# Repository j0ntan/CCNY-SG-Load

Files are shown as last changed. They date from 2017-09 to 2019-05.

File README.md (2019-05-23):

# CCNY Smart Grid Load

The Smart Grid Load (*SG-Load*) is a resistive, variable load component of the smart grid testbed at the Smart Grid Lab in the City College of New York. This project implements a control system for the SG-Load that allows:

* Setting the value of 3-phase AC loading to a balanced or unbalanced state.
* Varying the amount of loading for a DC source.
* Automating the amount of loading over time according to a load profile.

## Getting Started
This section summarizes the steps needed to upload the control system sketch to the Arduino and begin using the SG-Load through the keypad interface.\
*Note: The Arduino should already have the latest sketch version uploaded. The installation steps are only needed when debugging or upgrading this sketch.*

### Install & Run
1. [Download](https://github.com/j0ntan/CCNY-SG-Load/archive/master.zip) or clone ( `git clone https://github.com/j0ntan/CCNY-SG-Load.git` ) the repo into your **Arduino sketchbook location** directory, which may be under `{YourUserName}\Documents\Arduino` on a Windows machine.
2. Install the [New LiquidCrystal](https://bitbucket.org/fmalpartida/new-liquidcrystal) library, which replaces the usage of the default LCD library.
3. Open & upload the `CCNY_Smart_Grid_Load.ino` sketch using the Arduino IDE.
4. Switch the Arduino to external power and observe the LCD startup message to verify the sketch upload.

### Basic Input
The simplest way to control the SG-Load is with the front-panel keypad. Let's say we want to set up an unbalanced load at the AC terminals, with 10 switches turned ON for phases A & B, but only 9 for phase C. We can enter the sequence `A10B10C9`, or equivalently `AB10C9`, followed by the ENTER key (`#`), to activate this configuration.

The Arduino can also take input from an XBee-connected PC or the lab's dSPACE controller. These methods are slightly more complex and their descriptions are reserved for the wiki.

---
For further details on the installation & build process, system configurations and working with the SG-Load, check out the [wiki](https://github.com/j0ntan/CCNY-SG-Load/docs/wiki) documentation.

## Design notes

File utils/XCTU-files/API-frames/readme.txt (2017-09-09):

This directory contains frames that can be sent to an XBee device using the XCTU software by Digi. The frames contain a payload that is transmitted by the XBee device. This allows us to test different inputs by XBee transmission.

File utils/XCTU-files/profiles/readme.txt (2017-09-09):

This directory contains the XBee profiles for XBee devices connected to the Smart Grid Load and to a microgrid central controller (MGCC). Currently, the MGCC is a dSPACE controller. The current configuration uses the AT mode, for simplicity (refer to XBee docs regarding AT vs API mode). A future, more secure implementation will utilize the API mode with the built-in encryption.

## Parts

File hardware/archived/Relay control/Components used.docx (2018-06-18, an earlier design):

Components used:

Mux Shield (DEPRECATED)

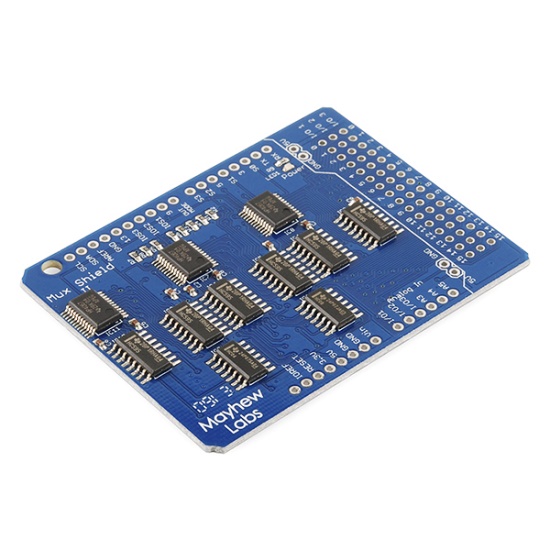
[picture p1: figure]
Mux Shield II

| User Guide (http://cdn.sparkfun.com/datasheets/Dev/Arduino/Shields/Mux_Shield_II_User_Guide.pdf) schematic (http://cdn.sparkfun.com/datasheets/Dev/Arduino/Shields/Mux_Shield_II_Rev0%20Schematic.pdf) Arduino library (http://cdn.sparkfun.com/datasheets/Dev/Arduino/Shields/MuxShield.zip)

74HCT373N OCTAL D TYPE TRANS LATCH, 3-STATE (DEPRECATED)

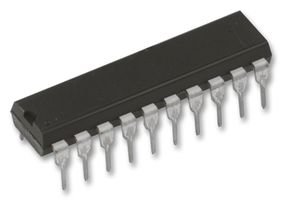
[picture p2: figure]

SainSmart IIC/I2C/TWI Serial 2004 20x4 LCD Module Shield for Arduino Raspberry Pi

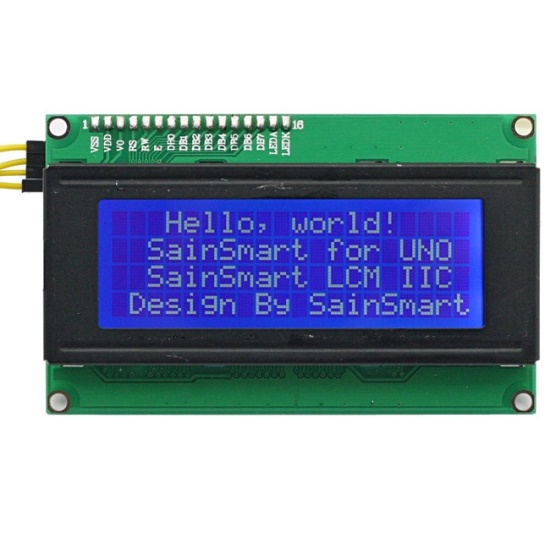
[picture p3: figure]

| module link (http://www.sainsmart.com/sainsmart-iic-i2c-twi-serial-2004-20x4-lcd-module-shield-for-arduino-uno-mega-r3.html) For using with Arduino, look at these links with libraries that are used in the relay code, instead of the default Arduino LCD library: 1 (https://bitbucket.org/fmalpartida/new-liquidcrystal/wiki/Home), 2 (https://bitbucket.org/fmalpartida/new-liquidcrystal/downloads), and 3 (https://bitbucket.org/fmalpartida/new-liquidcrystal/wiki/I2CIO). For connecting the module to Arduino, use the I2Cscanner code found here (http://arduinotronics.blogspot.com/2014/02/sainsmart-i2c-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

SainSmart 8 Channel DC 5V Relay Module for Arduino Raspberry Pi

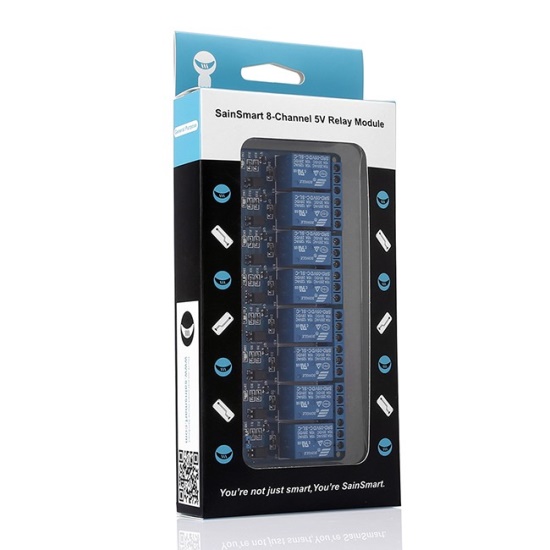
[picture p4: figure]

| module link (http://www.sainsmart.com/8-channel-dc-5v-relay-module-for-arduino-pic-arm-dsp-avr-msp430-ttl-logic.html) other docs (http://www.selloutsoon.com/albums/documents/20-018-102/8+Relay+Module.rar)

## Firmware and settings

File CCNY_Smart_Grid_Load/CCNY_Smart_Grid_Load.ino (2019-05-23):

// Author: Jonathan Gamboa
// version: 5.11.0
// Institution: Smart Grid Lab, City College of New York (ST 643)

#include "include/HardwareTimer.h"
#include "include/HardwareIO.h"
#include "include/HardwareKeypad.h"
#include "include/HardwareXBee.h"
#include "include/HardwareSDFlash.h"
#include "include/HardwareRNG.h"
#include "include/Display/HardwareLCD.h"
#include "include/InputSequence.h"
#include "include/LoadProfile.h"
#include "include/Monitor.h"
#include "include/Collect.h"
#include "include/RelayState.h"
#include "include/RelayStateGenerator.h"
#include "include/ShiftRegister.h"
#include "include/Output.h"
#include "include/Display/MessagesList.h"
#include "include/Display/StatusMsgSequences.h"

//
// SG-Load Arduino I/O pin mapping:
//
// Keypad outputs
const DigitalInput* row1 = new HardwareInput{37};
const DigitalInput* row2 = new HardwareInput{36};
const DigitalInput* row3 = new HardwareInput{35};
const DigitalInput* row4 = new HardwareInput{34};
const DigitalOutput* col1 = new HardwareOutput{33};
const DigitalOutput* col2 = new HardwareOutput{32};
const DigitalOutput* col3 = new HardwareOutput{31};
const DigitalOutput* col4 = new HardwareOutput{30};
const DigitalInput* input_pins[] = {row1, row2, row3, row4};
const DigitalOutput* output_pins[] = {col1, col2, col3, col4};
// Shift register outputs
const DigitalOutput* serial_data_output = new HardwareOutput{2};
const DigitalOutput* SR_clock_output = new HardwareOutput{3};
const DigitalOutput* ST_clock_output = new HardwareOutput{4};
// DC relay outputs
const DigitalOutput* relay1_output = new HardwareOutput{22};
const DigitalOutput* relay2_output = new HardwareOutput{23};

RelayState relay_state;
Timer* timer = new HardwareTimer;
Keypad* keypad = new HardwareKeypad{input_pins, output_pins};
ShiftRegister shiftregister{serial_data_output, SR_clock_output,
                            ST_clock_output};
XBee* xbee = new HardwareXBee{Serial};
SDFlash* sd = new HardwareSDFlash{53};
BernoulliRNG* rng = new HardwareRNG(0.2);
Display::LCD* lcd = new Display::HardwareLCD(0x27);

void setup() {
  Serial.begin(9600);
  Serial.setTimeout(10);
  Display::initializationSequence(*rng);
}

void loop() {
  InputSequence user_input;
  if (keypadButtonWasPressed()) {
    user_input = collectKeypadSequence();
    processInputSequence(user_input);
  } else if (xbee->hasBufferedData()) {
    if (receivedPCSerialData()) {
      user_input = collectPCSequence();
      processInputSequence(user_input);
    } else if (receivedDSPACEManualData()) {
      user_input = collectDSPACESequence();
      processInputSequence(user_input);
    } else if (receivedDSPACELoadProfile()) {
      activateLoadProfile();
    } else
      xbee->clearBuffer();
  }
}

void processInputSequence(const InputSequence& input) {
  if (isValidSequence(input)) {
    recordNewRelayState(input, relay_state);
    outputNewRelayState(relay_state);
    lcd->printMsg(Display::load_idle_state);
    Display::updateIdleState(relay_state);
  }
  // else, display error message
}

void activateLoadProfile() {
  unsigned int number = readRequestedProfileNumber();
  char filename[12] = {"PRFL000.txt"};
  createFilename(number, filename);

  if (sd->connected() && sd->fileExists(filename)) {
    LoadProfile profile{sd->openFile(filename)};
    while (profile.lineAvailable()) {
      InputSequence profile_input;
      unsigned long duration = 0;
      profile.readLine(profile_input, duration);
      processInputSequence(profile_input);
      timer->delay(duration);
    }
  } else
    lcd->printMsg(Display::SD_file_open_error);
}

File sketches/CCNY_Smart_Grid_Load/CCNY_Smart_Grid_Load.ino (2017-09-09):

// Author: Jonathan Gamboa
// version: 4.3
// Institution: Smart Grid Lab, City College of New York (ST 643)

#include <LoadEmulator.h>

void processInput(const String &);      // function prototype

HardwareSerial &xbee = Serial3;         // create an alias
Keypad keypad;                          // use default pins
Display disp(Serial, xbee, keypad);     // use default pins
SDprofile sd;                           // record SD connected status
ShiftRegister shiftReg(7, 5, 6, 4);     // chosen pins for shift register

Encoder encoder;

void setup() {
    Serial.begin(19200); Serial.setTimeout(10);
    xbee.begin(9600); xbee.setTimeout(10);
    shiftReg.begin();

    disp.begin(20, 4);                  // pass num of cols and rows

    // initialize DC relays
    pinMode(22, OUTPUT);
    pinMode(23, OUTPUT);
    digitalWrite(22, LOW);
    digitalWrite(23, LOW);

    // Done with Arduino initialization, now check SD card

    if(sd.checkConnected()==false) {
        String sdConnMsg;
        sdConnMsg.concat( F("    SD card not     ") );
        sdConnMsg.concat( F(" detected. Initial  ") );
        sdConnMsg.concat( F("check failed. Please") );
        sdConnMsg.concat( F("re-check connection.") );

        disp.showMessage(sdConnMsg, Display::Speed::SLOW);
    }

    // Done all initializations, go into idle state
    disp.showMessage(encoder.getIdleState(), Display::Speed::STATIC);
}

void loop() {
    if(keypad.isPressed()) {
        KeypadCol kCol(keypad);
        while(kCol.isCollecting())
            if(keypad.isPressed()) {
                kCol.collectKeypress();
                disp.showMessage(kCol.getColMsg(), kCol.getSpeed()); // update display
                kCol.waitKeyRelease();
            } // else do nothing in-between keypresses, until done collecting

        // send to scanner, etc...
        if(kCol.getInput().length()) processInput(kCol.getInput());
        else disp.showMessage(encoder.getIdleState(), Display::Speed::STATIC);
    } // end if, check keypad source
    else if(Serial.available()) {
        // allow buffer time to fill
        delay(10);

        SerialCol serCol(Serial.readString());
        disp.showMessage(serCol.getColMsg(), serCol.getSpeed()); // update display
        processInput(serCol.getInput());
    }
    else if(xbee.available()) {
        // allow buffer time to fill
        delay(200);

        if(xbee.available() < 12) { // dSPACE spams with data, User doesn't
            SerialCol xbCol(xbee.readString());
            disp.showMessage(xbCol.getColMsg(), xbCol.getSpeed()); // update display
            processInput(xbCol.getInput());
        }
        else {
            dspaceCol dsCol(xbee);
            if(dsCol.profileModeRequested()) {
                dsProfileCol dsPCol(xbee, sd);
                if(dsPCol.openFile()) {
                    disp.showMessage(dsPCol.getColMsg(), dsPCol.getSpeed());// display file opened msg

                    while(dsPCol.isCollecting())
                        if(dsPCol.readLine()) {
                            processInput(dsPCol.getInput());
                            delay(dsPCol.getDelay());
                        }
                }
                else {
                    disp.showMessage(dsPCol.getColMsg(), dsPCol.getSpeed()); // display error msg
                    disp.showMessage(encoder.getIdleState(), Display::Speed::STATIC);
                }
            }
            else {
                dsManualCol dsMC(xbee);

                while(dsMC.isCollecting()) {
                    dsMC.collectInt();
                    disp.showMessage(dsMC.getColMsg(), dsMC.getSpeed());
                }

                disp.showMessage(dsMC.getColMsg(), dsMC.getSpeed()); // display input or cancel msg
                if(dsMC.getInput().length()) processInput(dsMC.getInput());
                else disp.showMessage(encoder.getIdleState(), Display::Speed::STATIC);
            }
        } // end dspace collectors
    } // end else if xbee avail
}


void processInput(const String &input) {
    Scanner scanner;
        if(scanner.scan(input)) { // if scan successful
            Parser parser;
            if(parser.parse(scanner.getTokens())) { // if parse successful
                encoder.encode(parser.getSwitchingValues());

                // Activate AC relays
                shiftReg.outputData(encoder.getACEncodedValues(), 6);
                // Activate DC relays
                int relaysOn  = encoder.getDCValue();
                switch(relaysOn) {
                    case 0:
                        digitalWrite(22, LOW);
                        digitalWrite(23, LOW);
                        break;
                    case 1:
                        digitalWrite(22, HIGH);
                        digitalWrite(23, LOW);
                        break;
                    case 2:
                        digitalWrite(22, HIGH);
                        digitalWrite(23, HIGH);
                        break;
                };
            }
            else {
                disp.showMessage(parser.getErrMsg(), Display::Speed::NORMAL);
            }
        }
        else {
            disp.showMessage(scanner.getErrMsg(), Display::Speed::NORMAL);
        }
    disp.showMessage(encoder.getIdleState(), Display::Speed::STATIC);
}

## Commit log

2017-09-07 Initial implementation files
    File dump of the initial implementation. This work was done prior to
    using git, thus no history was saved. The same applies to tag 3.0.
    This implementation was a quick job, and so has very basic
    functionality and includes bugs. Saved for archive purposes only.
    [KeypadInput4x4.h, LCD20x04.h]
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2017-09-08 Inlcude ACTIVE_LOW option for shift registers
    This option was needed to accomodate the change in the type of relay
    module used. In the first implementation, the relays were active high.
    With the second implementation, the new relay voltage is compatible with
    Arduino, but is an active low logic.
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2017-09-08 Use input capture in main sketch
    The main sketch was slightly modified so that it can use the new input
    library, which tries to defragment the ways that input is sent to the
    Arduino. Previously, there was a seperate library for getting data from an
    XBee. Now, all the ways to give input to the Arduino is within a single
    library. A new feature includes using backspace function to make
    corrections. This simplifies the computation that the Arduino must do,
    especially when taking input from the keypad.
2017-09-08 Fix issue with RESET
    Fixes issue where the RESET functionality was working for AC relays, but not
    for DC relays.
2017-09-09 Add balanced input and profile modes
    Added a dSPACE balanced inupt mode. This mode allows a user to change the
    load to a balanced state with a single input, corresponding to the number
    of relays that should be ON with an offset.
    Added another dSPACE mode, profile mode, that allows the user to run a
    predefined load profile. Future implementation will allow the user to
    input the profile parameters.
2017-09-09 Move I2C scanner source link
    Removed the link to the Arduino site for the source code of this sketch.
    This link is provided in the documentation.
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2018-06-18 Rearrange header and source files
    Moved the files from the 'libraries' & 'sketches' directories to the
    root level. This eases the build process by removing the need to
    manually copy the 'libraries' files to the Arduino libraries path.
2018-06-18 Archive old board design files
    Added files of previous board implementations. These were done before
    use of version control, thus version tags embedded in the filenames.
    [BoardOutline.gbr, Bottom.gbr, Through.drl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]
2018-06-21 Remove Arduino library files
    These files are no longer needed after the rearrangement of the source
    files. They are only used when implementing an Arduino library, which
    is not the purpose of this repo.
2018-12-28 Remove previous library implementation
    Files removed includes:
    - keywords.txt
    - library.properties
    - header & source files (.h/.cpp)
    - example sketches
    In addition, the current implementation of the main sketch was removed
    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
2018-12-28 Create Arduino interface
    Added an interface for the hardware-dependent Arduino functions. This
    will improve the development process & allow unit testing on a host
    machine. Also included a 'Hardware-' class that calls the actual Arduino
    functions & a mock for testing.
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2018-12-28 Use Arduino interface in main sketch
    Added an interface instance to the main sketch for future use.
2018-12-28 Create Keypad interface
    Added an interface for a 4x4 matrix keypad, a 'Hardware-' class to
    interface with an actual device, and a mock class for testing.
2018-12-28 Add Monitor function for Keypad
    The Monitor functions are used in the Monitor stage when the Arduino is
    looking for user input. These functions are simply function wrappers
    that allow simplification in the main sketch where the functions are
    used and improves its readability.
2018-12-28 Add Collect functions for Keypad
    Added functions that handle the detection, identification & collection
    of button presses, using a string to store the input sequence.
2018-12-28 Create StringDouble class for use in tests
    Copies the Arduino String functionality for use in Google Test. This
    class mimics the String class used in Arduino sketches, but allows
    testing by using the standard library string implementation in place
    of the String class.
2018-12-28 Add RelayStates class
    Added a struct that simply holds a set of numberical values
    corresponding to the number of relays that are ON, per phase, at any
    point in the runtime.
2018-12-28 Test the Parse functions & remove sample inputs
    The tests for these functions utilize some sample strings that were
    previously kept in a text file. This file is removed after inlcuding the
    sample strings in the tests.
2018-12-28 Create XBee interface
    Added an interface for the XBee wireless radios, as well as a hardware-
    dependent wrapper class that uses the Arduino Serial port to read/write
    to the connected device.
2018-12-28 Add Monitor function for PC Serial mode
    Added a function to detect the receipt of an input sequence from a
    serial source. This project uses an XBee, in the transparent serial
    mode, connected to an Arduino Serial port to get input.
2018-12-28 Create LoadProfile interface
    Added an interface for reading load profiles, which are stored as plain
    text files, using the 'File' class in the Arduino SD library.
2018-12-28 Create SDCard interface
    Added an interface for an SD card class that uses the standard Arduino
    SD library to read files from a connected SD card module.
2018-12-28 Add i2c scanner sketch
    The scanner sketch is used to identify the I2C address of a device
    connected to the Arduino. It can be used to get the address of the LCD
    used in the load project.
2018-12-28 Create Display interface
    Added an inteface for the LCD used to display messages to the user about
    the input or status of the load. Also includes a 'Hardware-' class that
    uses the 'New LiquidCrystal' library by Francisco Malpartida
    (bitbucket.org/fmalpartida) to write to the connected display device.
2018-12-28 Add Display messages functions
    Added functions for displaying error or status messages, as needed, on
    the LCD connected to an Arduino.
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2019-01-03 Replace use of delay functions with Timer abstraction
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2019-01-11 Use DigitalIO within HardwareKeypad
    Replaces the Arduino-dependant funtions, within HardwareKeypad class,
    with those of the DigitalIO abstraction. Also includes some setup for
    the IO pins in the main sketch.
    Also removes the initialization function. It is no longer needed, as the
    pins are initilized before being passed unto the keypad instance.
    [CCNY_Smart_Grid_Load.ino]
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2019-01-18 Add InputSequence class
    This will replace the usage of the Arduino 'String' class for storing
    the user's input sequence. It utilizes the C standard library for future
    compatability with other platforms.
2019-01-18 Replace 'String' & 'StringDouble' w/ 'InputSequence'
    Some of the helper functions, in "Collect.h", were removed and replaced
    by the equivalent InputSequence methods.
    Tests in "Collect_tests.cpp" that called the functions removed from
    "Collect.h" were also removed.
    [CCNY_Smart_Grid_Load.ino]
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2019-01-26 Replace String filename with c-string
    [CCNY_Smart_Grid_Load.ino]
2019-01-26 Replace SDCard with SDFlash
    [CCNY_Smart_Grid_Load.ino]
2019-02-05 Refactor function for clearing XBee buffer
    The 'emptyTheBuffer' function was added to the XBee interface and its
    usage was replaced accordingly.
    [CCNY_Smart_Grid_Load.ino]
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2019-02-17 Rename relay state function
    A global relay state is needed to keep track of previous relay values.
    Without this, a shortened input sequence cannot produce a complete state
    for the relays. For example, if the input were "AB4" then we know that
    phases A and B will have 4 relays ON in the new state. But there is no
    indication of the previous values for phase C and DC relays, thus we
    cannot form a complete new relay state. This requires a rename and
    different signature for the relay state generator function.
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2019-02-20 Use relay state generator functions in main sketch
    Scan & parse files were removed and their functionality was replaced
    with the relay state generator functions.
    [CCNY_Smart_Grid_Load.ino]
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2019-02-22 Replace previous output function
    [CCNY_Smart_Grid_Load.ino]
2019-05-16 Add LCD interface
    Replaced old interface with one that uses the Message type to handle
    printing to the device.
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2019-05-21 Fix 'RelayStateGenerator' tests by adding LCD
